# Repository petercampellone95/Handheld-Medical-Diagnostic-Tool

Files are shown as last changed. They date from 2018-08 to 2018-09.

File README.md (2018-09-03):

# Handheld-Medical-Diagnostic-Tool
The Handheld Medical Diagnostic Tool or HMDT for short was a device created as the final project for a class on microprocessors. The goal of the HMDT was to create a simple handheld device capable of taking temperature measurements and reading the beats-per-minute (bpm) of a human heart in a small battery-powered form factor capable of lasting a full 8-hour day. The case was 3D printed using my own personal 3D printer and took about 7-8 design revisions for both the top and bottom cases. You can find some of the 3D model design files (.stl) in this repository to get an idea of the progression made through each of the revisions. 

Some of the features of the HMDT are as follows:

- 2000mAh LiPo Battery
- USB Charging
- Simple 16x2 Character LCD for measurement readout with tactile switch controlled menu-system 
- ATMEGA 328P 8-Bit AVR microcontroller
- MLX90614 IR Temperature Sensor (Front-Mounted)
- Clip-on IR Pulse Sensor
- Battery life readout and low battery warning message
- Ergonomic 3D printed case with similar dimensions to modern smartphones

*More technical details can be found in the final project report and other files within this repository*

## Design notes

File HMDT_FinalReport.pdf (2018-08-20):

Peter Campellone
May, 10 2015
ELE205/6 Final Project Report

Handheld Medical Diagnostic Tool

Abstract

The goal for my final project was to create a handheld device capable of taking multiple medical measurements and displaying them to the user in a timely fashion. Furthermore, this device was designed with the goal of being able to last a full work day of approximately 8-10 hours on a single charge. The measurements this device would be able to take are heart rate via a plugged in heart rate sensor and temperature via an IR sensor on the left face of the device. These measurements would then be displayed to the user via a 16x2 LCD which would be programmed with a menu system consisting of various options. The menu would be controlled via two tactile switches placed to the right of the LCD screen. All of these components would be housed inside a custom designed 3D printed case.

Methods

The first task for creating the handheld medical diagnostic tool (HMDT) was to create a bill-of-materials (BOM) of all the components and parts needed to create the device. Below in Figure 1 is the original BOM for this project.

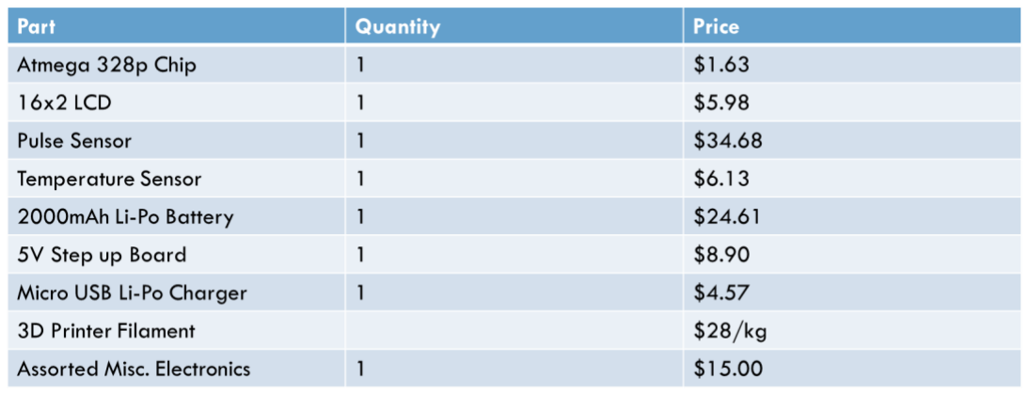
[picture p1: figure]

Figure 1. Original Bill-of-Materials

From the BOM the minimum total estimated cost of the HMDT to build would be $115.50, when figuring a usage of about 500g of 3D printer filament totaling $14.00 for the filament.

After creating the BOM and ordering the necessary parts the next step was to create the code that would run this project. All of the coding was done using the Arduino IDE exclusively, which helped keep everything simple. To run the LCD, Temperature Sensor, and Pulse Sensor it was decided that the best and easiest way was to use the open-source libraries that had been already created for these devices. For example, both the LCD and temperature sensor use the I²C communication protocol therefore instead of creating a new library and new code to make these devices work it was simplest to use the available open-source libraries. The library for the LCD, called “New Liquid Crystal” was provided by F. Malpartida and the library for the temp. sensor was provided by Adafruit Inc. Furthermore, the library and code for the pulse sensor was provided by World Famous Electronics LLC. (Credit and appropriate links is in final source code). Using these open-source libraries just made it much easier to get these devices up and running because nothing beats having openly available code that is known to work and work well at that. The rest of the code for the menu system, button reading, I/O, and other menu options is entirely unique and was created specifically for this project. Please find the final and fully documented source code included in the .ZIP file.

The next part of this project was to test the code and all of these devices together. The initial test would be done while running the entire project connected to the Arduino UNO. The second test would be done with the final board featuring the lone Atmega 328p Chip on a protoboard and all the connections to the other components. This second test is discussed later on in the report. Initial testing proved that the code I had created did in fact work besides for some minor display errors. In the end the code only needed minor tweaking in the form of modifying LCD output commands, introducing or changing delays, and optimizations. In the end the final code had four distinct modes as described in Figure 2. below.

Mode | Function | Other Functions:
1. All Off | Idle State, No Measurements | Turns off LCD backlight after 25 seconds (configurable)
2. Temp. Sensor | Turns on Temp. Sensor, Reads output from Temp. Sensor | Displays temperature value to LCD in Fahrenheit (configurable)
3. Pulse Sensor | Turns on Pulse Sensor, Reads output from Pulse Sensor | Displays heart rate to LCD in BPM
4. Battery Charge | Displays the current battery charge percentage. | Displays a message if the battery goes below 20%

Figure 2. HMBT Table of Modes and their Functions

After completing the code and testing the device with the Arduino Uno and a breadboard the next step was to design a case for the device. The case was modeled using a 3D CAD program called Tinkercad which is a simplified and free online version of Autodesk 123D Design. In the end six versions of both the top and bottom cases had been created for the HMBT. Overall, the first three iterations were for determining the general shape and overall design of the case while the last three were based on test fitting the components within the case and making changes. Below in Figure 3. are some of the case designs that were printed. In the .ZIP folder you will find the files for the final designs of the top and bottom case. These files can viewed at www.viewstl.com.

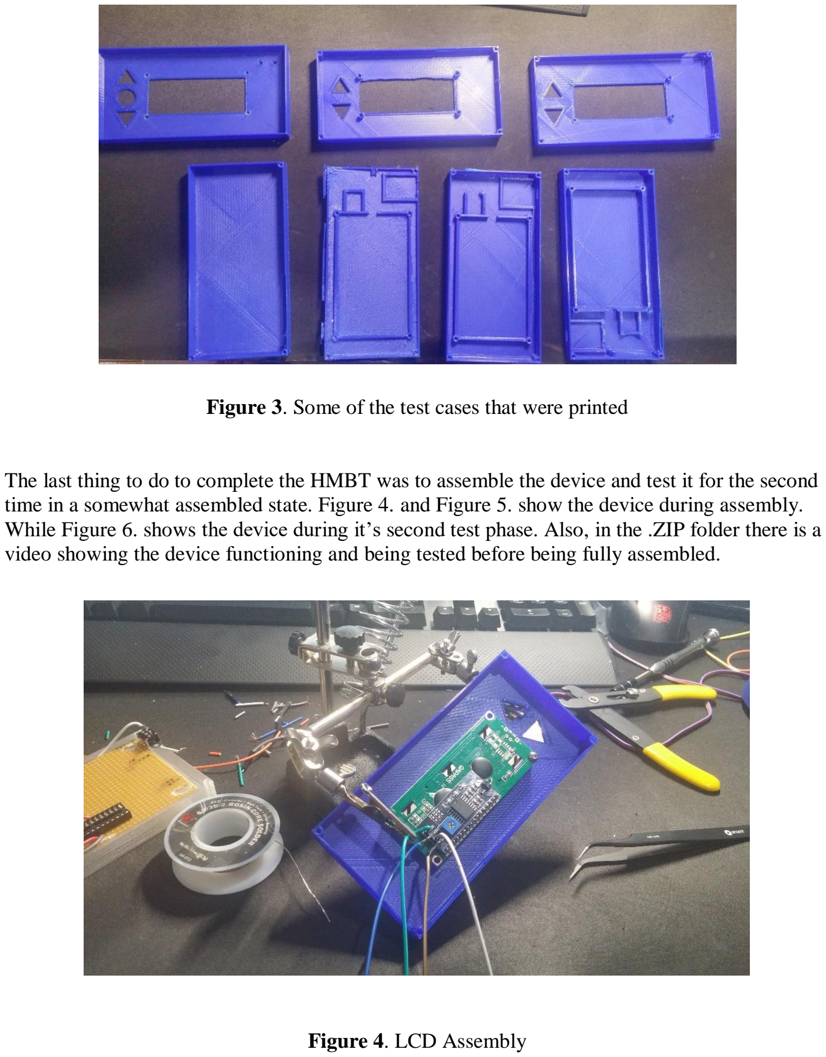
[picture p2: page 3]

Figure 3. Some of the test cases that were printed

The last thing to do to complete the HMBT was to assemble the device and test it for the second time in a somewhat assembled state. Figure 4. and Figure 5. show the device during assembly. While Figure 6. shows the device during it’s second test phase. Also, in the .ZIP folder there is a video showing the device functioning and being tested before being fully assembled.

Figure 4. LCD Assembly

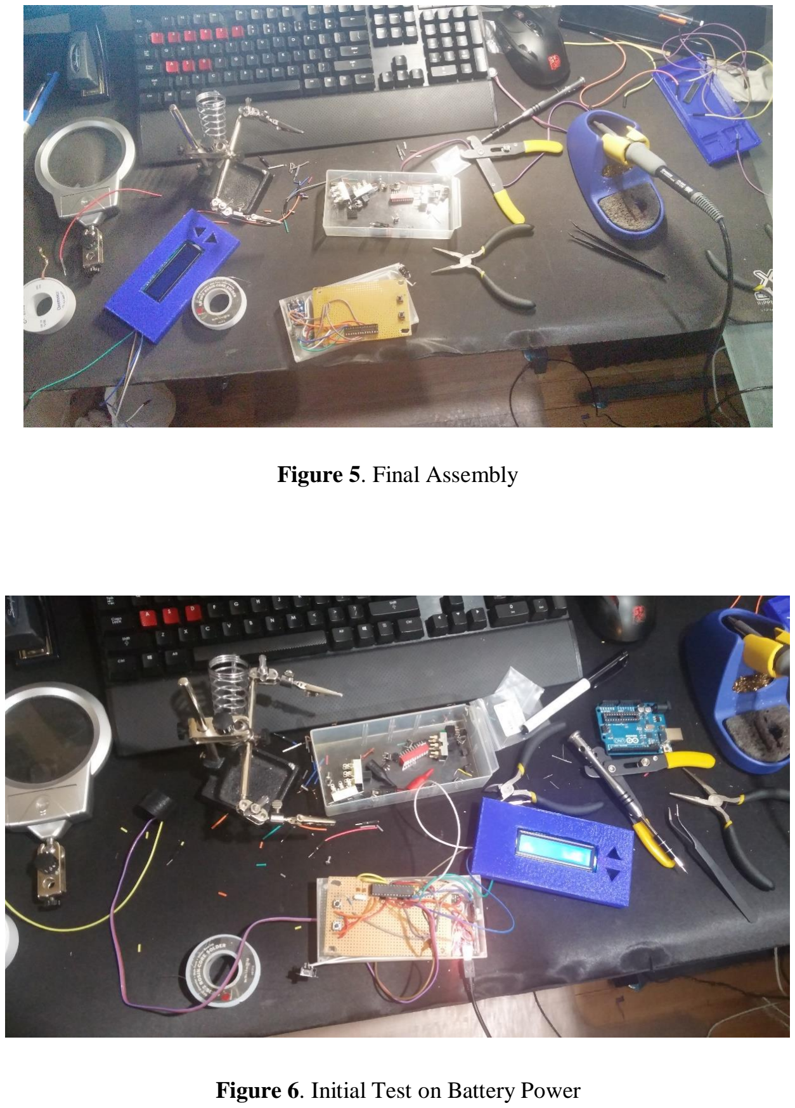
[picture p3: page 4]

Figure 5. Final Assembly

Figure 6. Initial Test on Battery Power

Results

Overall during testing the device functioned as desired and was able to take all measurements accurately and quickly at that. To be sure of this I compared the pulse sensor by first measuring my own heart rate with a stopwatch and then with the sensor. In the end the sensor was off by only +/- 1BPM compared to my own measurements and therefore is definitely a very accurate and precise device. Although, more testing would needed to be done using more proven methods than by using a stopwatch and counting. To test the heart rate sensor I compared it to a handheld IR thermometer. Comparing the readings of the two to the same objects resulted in differences of about +/- 0.5 °F across the board. Therefore, the temperature sensor as well is accurate and precise but again more scientific and rigorous testing would needed to be done to prove this. Finally, the battery charge meter was tested and compared to the readings of a multimeter. In order to calculate the percentage charge of the battery an analog pin on the Atmega 328p was connected to the positive lead of the battery and the voltage was measured. To calculate the percentage a mathematical function was created which relates the max voltage of the battery at full charge with what was considered the voltage of a dead battery. In this case, the max voltage of the LiPo battery was measured at 4.30V and the minimum voltage was measured at 3.70 V. Knowing these values the function below was created:

percentage =

(reading − 3. 70)
(4.30 − 3.70)

∗ 100

From testing this function did accurately calculate the percentage of charge remaining on the battery. Although, this value had a tendency to fluctuate by about +/- 10% in real time on the LCD. This is likely due to the fact that an analog pin was being used to measure this voltage which have been shown to not be entirely accurately. Also, there was likely electrical noise interfering with the reading given that neither the analog pin nor the wire were shielded. Regardless, the function was still able to give an idea of the remaining charge on the battery which is definitely a useful and integral function, especially in a medical environment.

Discussion

Overall the HMBT functioned above expectations in reference to accuracy and reliability; frankly better than I expected. In the end the final cost was only about eight dollars off of my estimate of $115.50. This can be seen in detail in Figure 7. which is the final BOM for the total project. Currently, the HMBT is disassembled given that the voltage regulator was shorted out accidentally and subsequently destroyed therefore I have been unable to actually finish and test the device in the field and in more strenuous circumstances than around the house. Regardless though, I am confident in the HMBT’s ability and I am not concerned about more intense testing given how it has performed thus far. The project in total was very enjoyable and I learned a considerable amount along the way. I plan on continuing to improve the design by coming up with a more altruistic case design, designing and having a custom PCB fabricated, adding a larger capacity battery, and using a more colorful and larger display. Overall though, in it’s current state I am very proud of the device and what it is capable of and more so what I have accomplished.

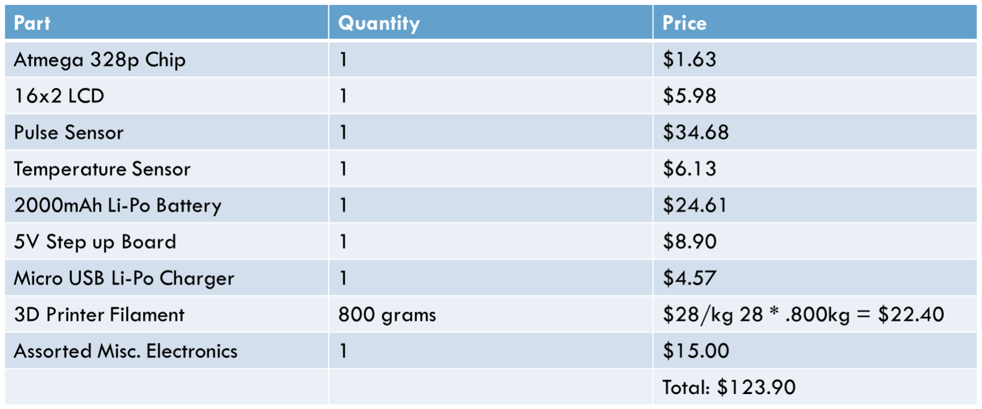
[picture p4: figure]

Figure 7. Final Bill-of-Materials

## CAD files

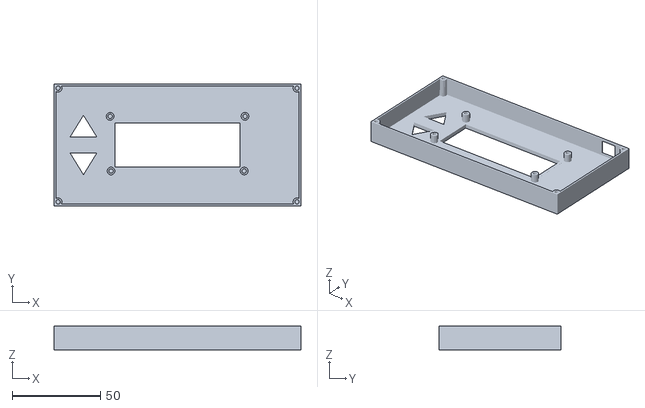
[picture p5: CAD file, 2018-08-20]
3D Models/STL/ele206project topv5_fixed.stl
140.1 x 69.0 x 13.5

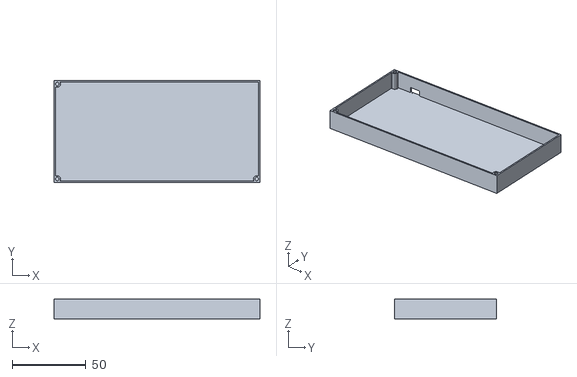
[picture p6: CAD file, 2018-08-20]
3D Models/STL/eleProjectTop.stl
140.0 x 69.0 x 13.5

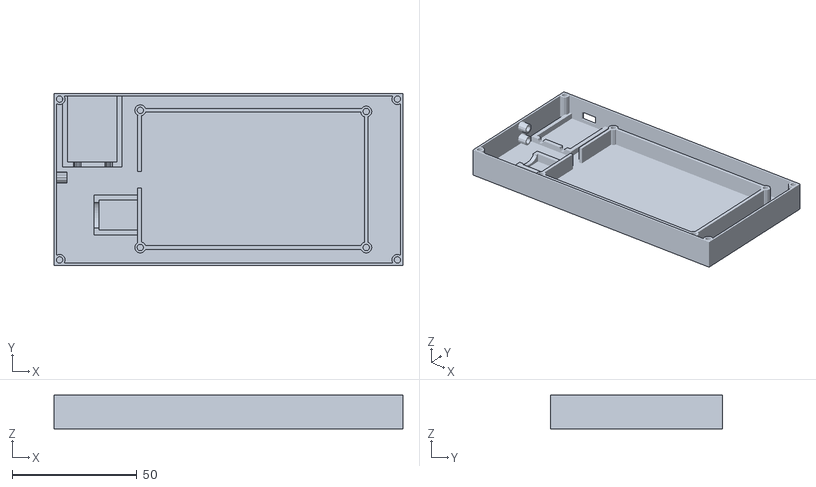
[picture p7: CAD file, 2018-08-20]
3D Models/STL/ELE206ProjectV4Bottom.stl
140.0 x 69.0 x 13.5

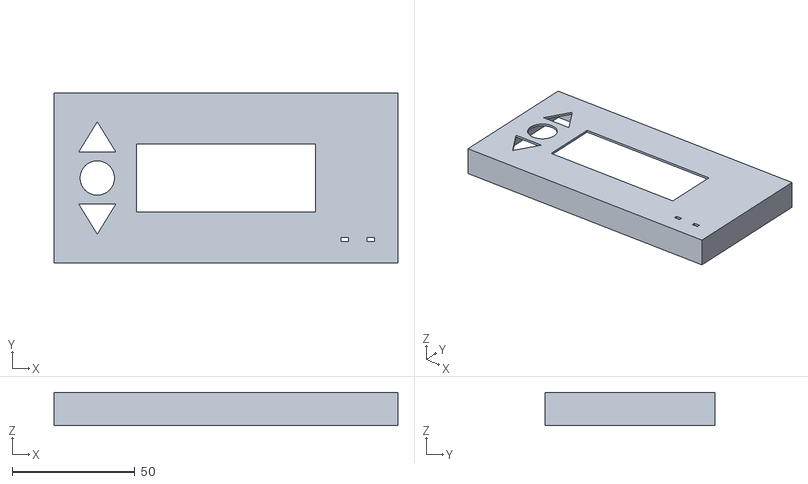
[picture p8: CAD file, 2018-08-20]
3D Models/STL/ele206project.stl
140.0 x 69.0 x 13.5

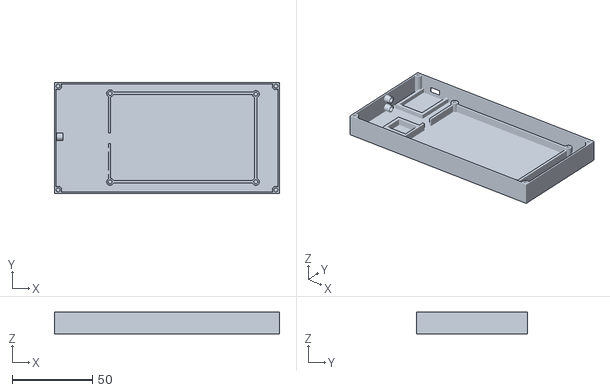
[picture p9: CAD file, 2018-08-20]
3D Models/STL/eleProjectV3FinalBottom.stl
140.0 x 69.0 x 13.5

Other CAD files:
3D Models/STL/ele206project topv5.stl
3D Models/STL/ELEProjectV5Top.stl
3D Models/STL/eleproject.stl
3D Models/STL/ELE206ProjectV3Top.stl
3D Models/STL/ELE206Project_Top_Final.stl
3D Models/STL/ELE206Project_Bottom_V6_Final.stl

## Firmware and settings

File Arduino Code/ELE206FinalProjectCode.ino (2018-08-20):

/******************************************************************
   Program Name: ELE 206 Final Project
   Created by: Peter M Campellone
   Date Created: 3/31/2016
   Program Description: This program is used to control a 3D
   printer handheld medical diagnostic tool. Tee functions of
   this device include IR temperature measurement and pulse rate
   measurement. These values are outputted to a 16x2 LCD connected
   using the I2C protocol made possible by a serial to parallel board
   specifically made for HD44780 controlled LCDs.
   Numerous parts of this code are taken from open-source
   libarires, etc. Credit for these portions is attributed below:

    Pulse Sensor Code: World Famous Electronics LLC. (https://github.com/WorldFamousElectronics/PulseSensor_Amped_Arduino)
    MLX90614 Code/Library: Adafruit Inc. (https://github.com/adafruit/Adafruit-MLX90614-Library)
    Serial I2C LCD Code: F. Malpartida (https://bitbucket.org/fmalpartida/new-liquidcrystal/wiki/Home)

    Pin Assignment:

    Pulse Sensor: A1 (Data)
    LCD: A4 (SDA), A5 (SCL)
    MLX90614: A4 (SDA), A5 (SCL)
    Buttons: 4 (Up), 5 (Down)
    Battery Meter: A3


 ******************************************************************/

//Libraries

#include <LiquidCrystal_I2C.h> //Open Source Library for controlling an LCD using I2C, provided by F. Malpartida
#include <Adafruit_MLX90614.h> //Adafruit's Open Source Library for the MLX90614 Temp. Sensor
#include <Wire.h> //Built-in Arduino library needed for using the I2C communication protocol

#define BACKLIGHT_PIN 3

LiquidCrystal_I2C  lcd(0x3F,2,1,0,4,5,6,7);
Adafruit_MLX90614 mlx = Adafruit_MLX90614(); //Setting up the MLX90614 library, The MLX90614 uses I2C which uses pins A4 and A5 (SDA, SCL)

//Menu System and Switch Variables
const int upButtonPin = 9; //The up button will be connected to digital pin 4
const int downButtonPin = 10; //The down button will be connected to digital pin 5

int lastButtonPushed = 0; //Stores the pin number of the last button pushed (either pin 4 or 5 in this case)

int upButtonLastState = LOW; //Stores the last state of the upButton (used to recognize button presses)
int downButtonLastState = LOW; //Stores the last state of the upButton (used to recognize button presses)

long upButtonDebounceTime = 0; //Long variable to store the debounce time of the up button
long downButtonDebounceTime = 0; //Long variable to store the debounce time of the down button

long debounceDelay = 250; //Long variable storing a typical delay to account for mechanical switch debounce, 350ms in this case works well

//Other variables
int mode = 0; //Modes, 0 = All off, 1 = Temp Sensor, 2 = Heart Rate Sensor, 3 = Battery Meter
const int batteryPin = A3; //Analog pin to read battery voltage

double tempF = 0; //Double variable storing the Fahrenheit temperature as outputted by the MLX90614
double voltage = 0; //Voltage of battery calculated from analog read on A3
int percentage = 0; //Percentage of charge left on battery

const int pulsePowerPin = 12;

long startTime = 0;
long endTime = 0;
long totalTime = 0;


//Pulse Sensor Pins
const int pulsePin = A1;                 // Pulse Sensor purple wire connected to analog pin 0

// Volatile Variables, used in the interrupt service routine!
volatile int BPM;                   // int that holds raw Analog in 0. updated every 2mS
volatile int Signal;                // holds the incoming raw data
volatile int IBI = 600;             // int that holds the time interval between beats! Must be seeded!
volatile boolean Pulse = false;     // "True" when User's live heartbeat is detected. "False" when not a "live beat".
volatile boolean QS = false;        // becomes true when Arduoino finds a beat.

static boolean serialVisual = false;   // Set to 'false' by Default.  Re-set to 'true' to see Arduino Serial Monitor ASCII Visual Pulse
// Only set to true for testing, disabled otherwise


void setup() {

  Serial.begin(115200);             //Turn on serial monitor at a baud rate of 115200 bps
  pinMode(batteryPin, INPUT);
  pinMode(upButtonPin, INPUT);      //pin that will be connected to the up button
  pinMode(downButtonPin, INPUT);    //pin that will be connected to the down button
  pinMode(pulsePowerPin, OUTPUT);

  lcd.setBacklightPin(BACKLIGHT_PIN,POSITIVE);
  lcd.setBacklight(HIGH);

  interruptSetup();// sets up to read Pulse Sensor signal every 2mS
  // may want to move down to case statement, see if location causes time delays
  lcd.begin(16, 2); //Intializing a 16 row by 2 column LCD
  mlx.begin();      //Intializing the MLX90614 temperature sensor

  lcd.setCursor(0,0);
  lcd.println("Handheld Medical");
  lcd.setCursor(0,1);
  lcd.println("Diagnostic Tool ");
  delay(2000);
 

}


void loop() {

  readButtons(); //Calls readButtons()to check if a button has been pressed
  moveMenu();   //Calls moveMenu() to move the LCD menu if a button has been pressed
  modeOutput(); //Tells the tool to perform a specific function based on switch input

}

void readButtons() {
  //Function used to check if the up or down buttons were pressed, incorporates debounce calcualtions to improve stability

  int reading;                //Integer variable to store the digital reading from the two switches
  int upButtonState = LOW;    //Integer variable to store the current state of the up button
  int downButtonState = LOW;  //Integer variable to store the current state of the down button

  //Checking if the up button was pressed
  reading = digitalRead(upButtonPin);

  if (reading != upButtonLastState) //If the reading is different the previous state the button has changed
  {
    upButtonDebounceTime = millis(); //Start a timer to calculate debounce
  }

  if ((millis() - upButtonDebounceTime) > debounceDelay) //If the was pressed longer than the debounce delay then it was an actual button press
  {
    upButtonState = reading; //Set the up button state to the reading on pin 4
    upButtonDebounceTime = millis(); //Set the debounce time for the up button equal to millis(), effectively the debounce delay of the up button
  }

  upButtonLastState = reading; //Set the last state of the up button equal to variable reading

  //Checking to see if the down button was pressed
  reading = digitalRead(downButtonPin);

  if (reading != downButtonLastState) //If the reading is different the previous state the button has changed
  {
    downButtonDebounceTime = millis(); //Start a timer to calculate debounce
  }

  if ((millis() - downButtonDebounceTime) > debounceDelay) //If the was pressed longer than the debounce delay then it was an actual button press
  {
    downButtonState = reading; //Set the up button state to the reading on pin 5
    downButtonDebounceTime = millis(); //Set the debounce time for the down button equal to millis(), effectively the debounce delay of the down button
  }

  downButtonLastState = reading; //Set the last state of the down button equal to variable reading

  //Reporting which button was pushed

  if (upButtonState == HIGH) {
    lastButtonPushed = upButtonPin;
    Serial.println("Up Button Pushed");

  }
  else if (downButtonState == HIGH) {
    lastButtonPushed = downButtonPin;
    Serial.println("Down Button Pushed");
  }

  else {
    lastButtonPushed = 0; //No button was pushed
  }
}

boolean moveMenu() {
  //Boolean function used to change the mode based on whatever the last button pushed was

  if (lastButtonPushed == upButtonPin) //If the last button pushed was the up button then increment mode and return true
  {
    delay(100);
    mode++; //Increment mode
    return true; //True means a button was pushed regardless of which one it was
  }

  if (lastButtonPushed == downButtonPin) //If the last button pushed was the down button then decrement mode and return true
  {
    delay(100);
    mode--; //Decrement mode
    return true;//True means a button was pushed regardless of which one it was
  }

  lastButtonPushed = 0; //Neither button was pushed
  return false; //Return false meaning that no button was pushed and that the mode shouldn't change
}


void modeOutput() {
  //Function used to perform various functions depending on the current value of mode
  //Current functions are: Mode 0: All off
  //                       Mode 1: Temperature Measurement
  //                       Mode 2: Pulse Rate Measurement
  //                       Mode 3: Battery Meter

  lcd.setCursor(0,1);
  lcd.println("                ");

  if (mode < 0) //If mode is less than zero than it is out of bounds and will be set to 2
  {
    mode = 3;
  }

  if (mode > 3) //If mode is greater than two then it is out of bounds and will be set to 0
  {
    mode = 0;
  }

  switch (mode) //Switch-Case statement used to switch between different modes
  {
    case 0: //If Mode = 0, All Off

      startTime = millis();
      digitalWrite(pulsePowerPin,LOW);
      lcd.setCursor(0,0);
      lcd.println("    All Off     "); //Prints message to LCD that all modes are off
      endTime += millis() - startTime; 
      Serial.println(endTime);
      if(endTime >= 15000)
      {
        lcd.setBacklight(LOW);
        break;
      }
      break;

    case 1: //If Mode = 1, Use the Temp. Sensor
    
      endTime = 0;
      lcd.setBacklight(HIGH);
      digitalWrite(pulsePowerPin,LOW);
      delay(20);
      tempF = readTemp(); //Read the temperature in Fahrenheit from the temp. sensor
      lcd.setCursor(0, 0);
      lcd.print("Temp:");
      lcd.print(tempF+2);
      lcd.write(0xDF);
    lcd.println("F    ");
      delay(200); //100 ms delay so that the value on the LCD is readable

      readButtons(); //Check for button presses after each iteration
      moveMenu(); //Move menu if there was a button pressed

      break;

    case 2: //If Mode = 2, Use the Pulse Sensor
      
      endTime = 0;
      lcd.setBacklight(HIGH);
      digitalWrite(pulsePowerPin,HIGH);
      delay(20);
      getPulse(); //Calls the getPulse() function which gets the pulse rate from the pulse sensor
      lcd.setCursor(0, 0);
      lcd.print("H. Rate: ");
      lcd.print(BPM);
      lcd.println("BPM   ");
      delay(200);

      readButtons(); //Check for button presses after each iteration
      moveMenu(); //Move menu if there was a button pressed

      break;


    case 3:
    
      endTime = 0;
      lcd.setBacklight(HIGH);
      digitalWrite(pulsePowerPin,LOW);
      batteryMeter();
      lcd.setCursor(0, 0);
      lcd.print("Bat. Charge:");
      lcd.print(percentage);
      lcd.println("%  ");

      delay(400);
      
 
      if (percentage <= 20)
      {
        lcd.setCursor(1, 1);
        lcd.println(" LOW BATTERY!  ");
      }

      else{
        lcd.setCursor(0,1);
        lcd.println("                ");
      }

      readButtons();
      moveMenu();

      break;

  }
}

double readTemp() {
  //Function used to read the temperature reported by the MLX90614

  return (mlx.readObjectTempF());

  //Serial.print("*F\tObject = "); Serial.print(mlx.readObjectTempF()); Serial.println("*F");
  //delay(500);
}

void getPulse() {
  //Function used to get the pulse rate from the pulse sensor
  //Slightly modified version of the pulse sensor code provided by World Famous Electronics LLC.

  serialOutput() ;

  if (QS == true) {    // A Heartbeat Was Found
    // BPM and IBI have been Determined
    // Quantified Self "QS" true when arduino finds a heartbeat
   
    // Set 'fadeRate' Variable to 255 to fade LED with pulse
    serialOutputWhenBeatHappens();   // A Beat Happened, Output that to serial.
    QS = false;                      // reset the Quantified Self flag for next time
  }
  delay(20);                             //  take a break
}

void batteryMeter() {
  //Function used to calculate the amount of charge left on the battery. For single cell LiPo batteries max is 4.20V and min is 3.70V.

  int reading = analogRead(batteryPin);
  Serial.println(reading);
  voltage = (5.0 / 1023) * reading;
  Serial.println(voltage);
  percentage = ((voltage - 3.70) / (4.30 - 3.70)) * 100;

}
 
//END OF PROGRAM

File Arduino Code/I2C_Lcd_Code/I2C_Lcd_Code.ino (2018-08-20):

/*
** Example Arduino sketch for SainSmart I2C LCD Screen 16x2
** based on https://bitbucket.org/celem/sainsmart-i2c-lcd/src/3adf8e0d2443/sainlcdtest.ino
** by
** Edward Comer
** LICENSE: GNU General Public License, version 3 (GPL-3.0)

** This example uses F Malpartida's NewLiquidCrystal library. Obtain from:
** https://bitbucket.org/fmalpartida/new-liquidcrystal 

** Modified - Ian Brennan ianbren at hotmail.com 23-10-2012 to support Tutorial posted to Arduino.cc

** Written for and tested with Arduino 1.0
**
** NOTE: Tested on Arduino Uno whose I2C pins are A4==SDA, A5==SCL

*/
#include <Wire.h>
#include <LCD.h>
#include <LiquidCrystal_I2C.h>

#define I2C_ADDR    0x3F // <<----- Add your address here.  Find it from I2C Scanner
#define BACKLIGHT_PIN     3
#define En_pin  2
#define Rw_pin  1
#define Rs_pin  0
#define D4_pin  4
#define D5_pin  5
#define D6_pin  6
#define D7_pin  7

int n = 1;

LiquidCrystal_I2C  lcd(I2C_ADDR,En_pin,Rw_pin,Rs_pin,D4_pin,D5_pin,D6_pin,D7_pin);

void setup()
{
 lcd.begin (16,2); //  <<----- My LCD was 16x2

 
// Switch on the backlight
lcd.setBacklightPin(BACKLIGHT_PIN,POSITIVE);
lcd.setBacklight(HIGH);

lcd.home (); // go home

 lcd.print("SainSmartI2C16x2");  
}

void loop()
{

}
